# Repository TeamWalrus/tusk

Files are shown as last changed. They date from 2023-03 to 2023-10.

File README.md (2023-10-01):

# Tusk: Revamping an old weaponised RFID reader tool

This repo contains the hardware and software upgrades made to the original [Tastic RFID Thief project](https://bishopfox.com/resources/rfid-hacking-intro-to-tastic-rfid-thief), which was created by Francis Brown at Bishop Fox.

The core functionality of the project remains the same: a tool that allows red teamers to capture RFID access card credentials from several feet away. Additionally, the same readers are supported:

- HID Maxiprox 5375 (125kHz HID ProxII cards)
- HID Indala ASR-620 (125kHz Indala cards)
- HID iCLASS R90 (13.56mHz iClass cards)

## Overview of the upgrades

| Component | Description |
|:--- |:--- |
| Microcontroller Unit (MCU) | Replace the Arduino with an ESP32 |
| Batteries | Replace the AA with 27100's for the reader and 18650's for the MCU |
| Wireless Connectivity | The ESP32 has built-in WiFI capability |
| Web App | Simple react web interface |
| ~~Capability~~ | ~~Decode Gallagher 125kHz proximity cards (Cardax proprietary format)~~ |
| ~~Enclosure~~ | ~~3D printed enclosure for the PCB\*~~ |

\* One of the main issues with all previous build's I've seen, is the electronic components (microcontroller unit, buck converter and batteries) being housed inside the RFID reader. These components (specifically buck converters) create a lot of 'RF noise' - which interfere with the finely tuned RFID readers. This reduces the effective range of the reader, which can be the difference between capturing access card credentials or not. Housing these components externally, ensures the device operates at it's advertised range capability.

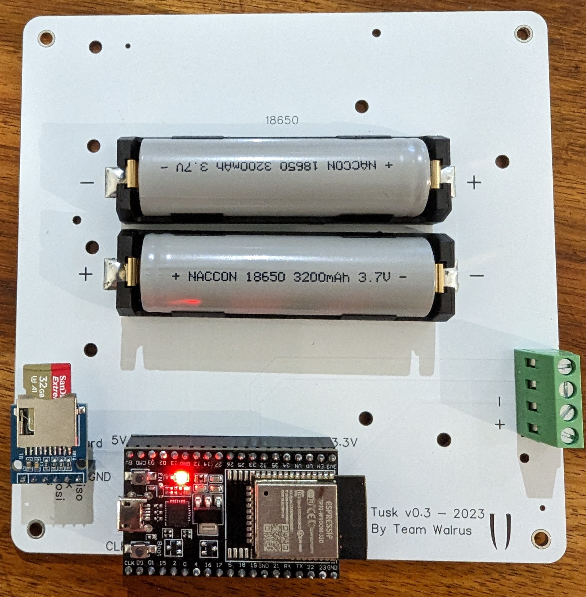
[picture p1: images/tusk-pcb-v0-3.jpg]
tusk-pcb


## Overview of the project structure

```
├── firmware                    # 
│   ├── interface               # react frontend web application
│   │   └── src
│   ├── data                    # build path of the react frontend
│   ├── src
│   │   └── main.cpp            # backend webserver + card handling code
│   ├── scripts
│   │   └── build_interface.py  # helper script to deploy react frontend to build path
├── hardware                    # gerber files, BOM, etc
```

## Build instructions: hardware

Gerber files, Bill of Materials (BOM), and Pick and Place files required to get the PCB manufactured can be found in the `/hardware` directory. This is a PCB that houses the batteries for the long range reader, ESP32 microcontroller unit, and sd-card reader. Note - some parts are not in the BOM as they were purchased directly from aliexpress (non-affiliate links below):

- ESP32-DevkitC-v4: https://www.aliexpress.com/item/4000090521976.html
- Mini SD card reader module: https://www.aliexpress.com/item/1865616455.html
- 21700 battery holder: https://www.aliexpress.com/item/1005003204083647.html

The tusk PCB uses 5 x 27100 li-ion batteries slots that will power the long range reader. That means the output voltage is 4.2V x 5 = 21V. This should be within the operating voltage for the long range readers listed above. However, I recommend checking this before hooking up your reader.

Once the PCB is assembled: 

- Connect the power from the PCB -> positive (+) and negative (-) from the block connector to the external reader
- Connect the data lines (`data0` and `data1`) from the block connector to the external reader

**Note**: the ESP32 footprint on the PCB is for an ESP32-DevKitC-V4. Older ESP32-DevKit-V1 will not fit.

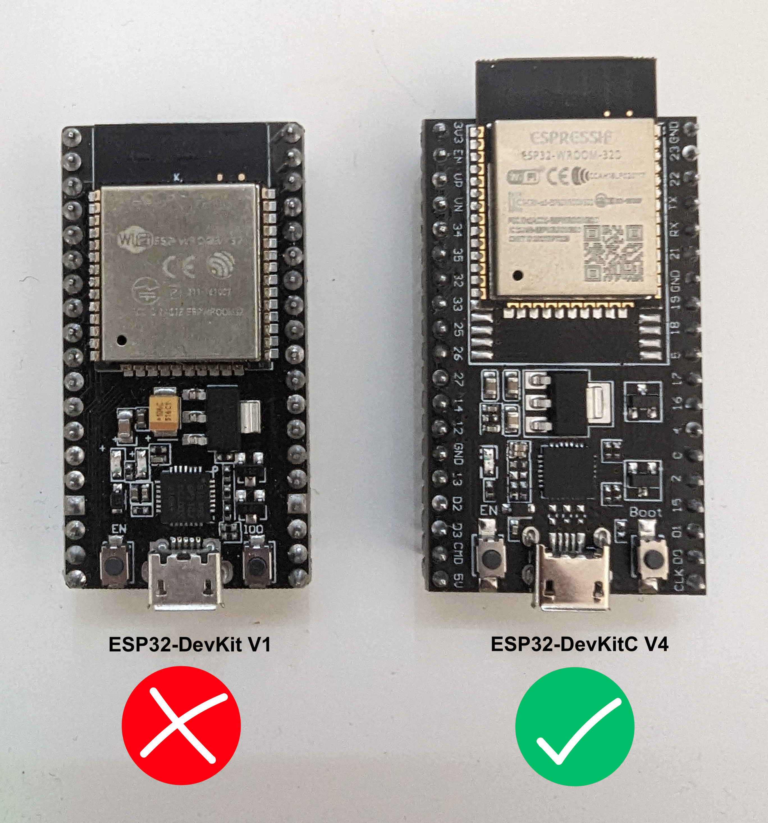
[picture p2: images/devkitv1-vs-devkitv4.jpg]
devkitv1-vs-devkitv4


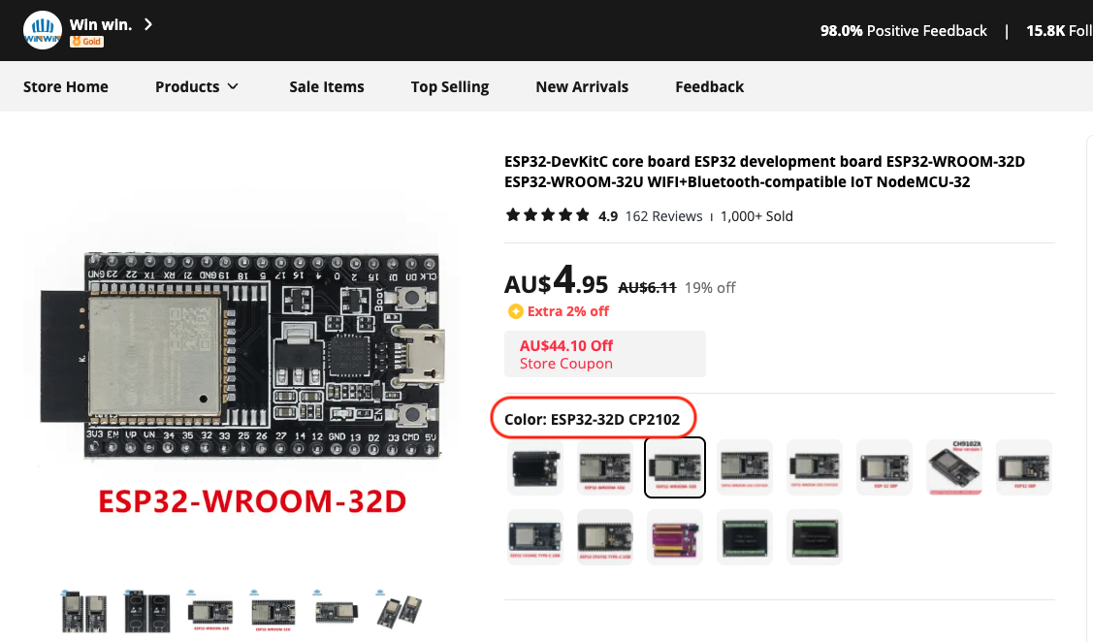
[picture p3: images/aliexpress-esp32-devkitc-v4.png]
aliexpress-esp32-devkitc-v4


## Build instructions: firmware

| Component | Description |
|:--- |:--- |
| `/firmware/src/main.cpp` | backend webserver and access card credentials handling code |
| `/firmware/interface/` | react frontend to display captured access card credentials  |

Change directory into `/firmware` and execute the following commands to flash the ESP32 firmware:

To build and upload the backend code: 

`pio run --target upload`

To build and upload the frontend react webapp: 

`pio run --target uploadfs`

### Tusk web interface

Clients connect to the ESP32 over WiFi and view captured card credentials via a react web application. The default values are as follows:

| Component | Details |
|:--- |:--- |
| WiFi SSID | `Tusk` |
| WiFi Password | `changeme` |
| URL | `http://192.168.100.1` |

## Legacy Operating Mode vs Future Operating Mode

The project currently operates in "legacy mode", which is based on receiving card credentials from the `data0` and `data1` output pins on the Maxiprox reader. 

This will eventually change and data will be sampled directly from the reader's microcontroller (pin `PD7` in the image below). The card sampling code is currently in another repo: https://github.com/TeamWalrus/tusk-sampler , and needs a few kinks ironed out. If you are interested in helping out, please check it out.

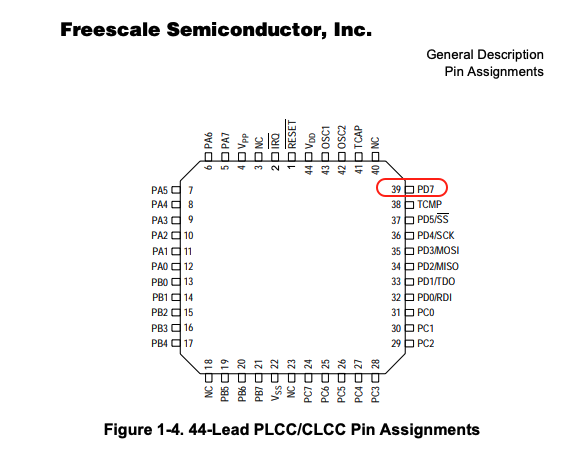
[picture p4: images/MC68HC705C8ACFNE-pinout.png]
MC68HC705C8ACFNE-pinout


Link for the MC68HC705C8ACFNE datasheet: https://www.allaboutcircuits.com/electronic-components/datasheet/MC68HC705C8ACFNE--NXP-Semiconductors/

## Acknowledgments

It's important to acknowledge previous work done on this project:

- Fran Brown: original Tastic RFID Thief: `https://www.bishopfox.com/resources/tools/rfid-hacking/attack-tools/`
- Folks who updated the original Arduino code:
  - ninewires: `https://github.com/ninewires/Prox_Thief/blob/master/Prox_Thief.ino`
  - ShakataGaNai: `https://gist.github.com/ShakataGaNai/4319d3e82a858c9d00c1d80f20da81a3`
- Other interesting projects / upgraded versions of the RFID Thief:
  - Mike Kelly's Wiegotcha: `https://github.com/lixmk/Wiegotcha`
  - Corey Harding's ESP-RFID-Thief: `https://github.com/exploitagency/ESP-RFID-Thief`

Thanks to my mate @megabug for always helping out with my projects :)

Thanks to my employer [Aura Information Security](https://www.aurainfosec.com/) for providing time for me to work on this project.

aura-logo

## Captured access card credentials format

Captured card credentials are written to the sd card in newline-delimited JSON (`cards.jsonl`). For example:

```
{"card_type":"hid","bit_length":26,"facility_code":123,"card_number":123123,"hex":"AAAAAAA","raw":"0010101010010011000101010"}
{"card_type":"gallagher","region_code":4,"bit_length":46,"facility_code":2222,"card_number":1111,"issue_level":3,"hex":"A38A8A4BA3A3A32C","raw":"101000110100010101100010101010010110101000110101000110101000110001011001"}
```

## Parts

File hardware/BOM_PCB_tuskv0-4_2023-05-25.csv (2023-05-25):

ID | Name | Designator | Footprint | Quantity | Manufacturer Part | Manufacturer | Supplier | Supplier Part | Price
1 | 21700 Battery Holder | U3,U6,U7,U8,U9 | 21700 BATTERY HOLDER | 5 | N/A | N/A | AliExpress | N/A
2 | PM254V-11-06-H85 | H1 | HDR-TH_6P-P2.54-V-F | 1 | PM254V-11-06-H85 | XFCN(兴飞) | LCSC | C2832269 | 0.119
3 | PM254-1-19-Z-8.5 | U1,U2 | HDR-TH_19P-P2.54-V-F | 2 | PM254-1-19-Z-8.5 | HCTL(华灿天禄) | LCSC | C2897382 | 0.272
4 | DB128V-5.0-4P | U5 | CONN-TH_DB128V-5.0-4P | 1 | DB128V-5.0-4P-GN-S | DIBO(地博电气) | LCSC | C424682 | 0.285
5 | BH-18650-B1BA002 | BT1,BT2 | BATTERY-SMD_18650-1S-L77.1-W20.7-1 | 2 | BH-18650-B1BA002 | MYOUNG(美阳) | LCSC | C2988620 | 1.33

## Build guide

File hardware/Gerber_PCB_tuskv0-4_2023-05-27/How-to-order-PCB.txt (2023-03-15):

How to Order PCB

Please refer to:
https://docs.easyeda.com/en/PCB/Order-PCB

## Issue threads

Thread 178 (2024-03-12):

Adding Debug instructions to README.md

evildaemond, 2024-03-12:
Adding some lines to the README.md file to assist with debugging, turns out SD Cards suck...

```text
### Debugging

The `sdCommand(): Card Failed! cmd: 0x00` error appears when the Micro SD does not connect to the ESP32

1. Check to make sure the Micro SD Card is installed
1. Using the continuity test on a Multimeter, verify if all traces are soldered properly

In the event of an error log which shows `sdcard_mount(): f_mount failed: (3) The physical drive cannot work`,

1. Make sure your Micro SD Card is formatted to FAT32
1. Check the Micro SD Card is suitable (Some forms of SanDisk SD cards such as the 32gb range will silently fail with this error)
```

dunderhay, 2024-11-12:
Awesome done!

Sorry only saw this now

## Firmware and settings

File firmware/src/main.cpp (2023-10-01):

// vim: ts=2 sw=2 et

#include "ArduinoJson.h"
#include "AsyncJson.h"
#include <Arduino.h>
#include <ESPAsyncWebServer.h>
#include <LittleFS.h>
#include <SD.h>
#include <SPI.h>
#include <WiFi.h>

// wifi config
// variables to save values from HTML form
String ssid;
String password;
String channel;
String hidessid;

// file paths on SD card to save wifi values permanently
const char *ssidPath = "/ssid.txt";
const char *passwordPath = "/password.txt";
const char *channelPath = "/channel.txt";
const char *hidessidPath = "/hidessid.txt";
const char *jsoncarddataPath = "/cards.jsonl";

IPAddress local_ip(192, 168, 100, 1);
IPAddress gateway(192, 168, 100, 1);
IPAddress subnet(255, 255, 255, 0);

// define CS pin for the SD card module
const int sd_cs = 5;

// general device settings
bool isCapturing = true;
String version = "0.1";

// read file from SD Card
String readSDFileLF(const char *path) {
  File file = SD.open(path);
  if (!file || file.isDirectory()) {
    Serial.println("[-] Failed to open file for reading");
    return String();
  }

  String fileContent;
  while (file.available()) {
    fileContent = file.readStringUntil('\n');
    break;
  }
  return fileContent;
  file.close();
}

// write file to SD Card
void writeSDFile(const char *path, const char *message) {
  File file = SD.open(path, FILE_WRITE);
  if (!file) {
    Serial.println("[-] Failed to open file for writing");
    return;
  }
  if (file.print(message)) {
    Serial.println("[+] File written");
  } else {
    Serial.println("[-] File write failed");
  }
  file.close();
}

// card reader config and variables

// max number of bits
#define MAX_BITS 100
// time to wait for another weigand pulse
#define WEIGAND_WAIT_TIME 3000

// stores all of the data bits
volatile unsigned char databits[MAX_BITS];
volatile unsigned int bitCount = 0;
// stores the last written card's data bits
unsigned char lastWrittenDatabits[MAX_BITS];
unsigned int lastWrittenBitCount = 0;

// goes low when data is currently being captured
volatile unsigned char flagDone;

// countdown until we assume there are no more bits
volatile unsigned int weigandCounter;

// card type
enum CardType {
  HID,
  GALLAGHER,
  UNKNOWN,
};
CardType cardType = UNKNOWN;

const char* cardTypeToString(CardType cardType) {
  switch (cardType) {
    case HID:
      return "hid";
    case GALLAGHER:
      return "gallagher";
    case UNKNOWN:
      return "unknown";
    default:
      return "Invalid Card Type";
  }
}

// decoded facility code
unsigned long facilityCode = 0;
// decoded card code
unsigned long cardNumber = 0;
// decoded issuer level
unsigned long regionCode = 0;
// decoded card code
unsigned long issueLevel = 0;
// hex data string
String hexCardData;
// raw data string
String rawCardData;

// breaking up card value into 2 chunks to create 10 char HEX value
volatile unsigned long bitHolder1 = 0;
volatile unsigned long bitHolder2 = 0;
unsigned long cardChunk1 = 0;
unsigned long cardChunk2 = 0;

// Define reader input pins
// card reader DATA0
#define DATA0 32
// card reader DATA1
#define DATA1 33

// process interupts
// interrupt that happens when INT0 goes low (0 bit)
void ISR_INT0() {
  bitCount++;
  flagDone = 0;

  if (bitCount < 23) {
    bitHolder1 = bitHolder1 << 1;
  } else {
    bitHolder2 = bitHolder2 << 1;
  }
  weigandCounter = WEIGAND_WAIT_TIME;
}

// interrupt that happens when INT1 goes low (1 bit)
void ISR_INT1() {
  if (bitCount < MAX_BITS) {
    databits[bitCount] = 1;
    bitCount++;
  }
  flagDone = 0;

  if (bitCount < 23) {
    bitHolder1 = bitHolder1 << 1;
    bitHolder1 |= 1;
  } else {
    bitHolder2 = bitHolder2 << 1;
    bitHolder2 |= 1;
  }

  weigandCounter = WEIGAND_WAIT_TIME;
}

// Print bits to serial (for debugging only)
void printCardData() {
  // ranges for "valid" bitCount are a bit larger for debugging
  if (bitCount > 20 && bitCount < 120) { // ignore data caused by noise
    Serial.print("[*] Bit length: ");
    Serial.println(bitCount);
    Serial.print("[*] Facility code: ");
    Serial.println(facilityCode);
    Serial.print("[*] Card number: ");
    Serial.println(cardNumber);
    if (cardType == GALLAGHER) {
      Serial.print("[*] Region Code: ");
      Serial.println(regionCode);
      Serial.print("[*] Issue Level: ");
      Serial.println(issueLevel);
    }
    Serial.print("[*] Hex: ");
    Serial.println(hexCardData);
    Serial.print("[*] Raw: ");
    Serial.println(rawCardData);
  }
}

// Process hid cards
unsigned long decodeHIDFacilityCode(unsigned int start, unsigned int end) {
  unsigned long HIDFacilityCode = 0;
  for (unsigned int i = start; i < end; i++) {
    HIDFacilityCode = (HIDFacilityCode << 1) | databits[i];
  }
  return HIDFacilityCode;
}

unsigned long decodeHIDCardNumber(unsigned int start, unsigned int end) {
  unsigned long HIDCardNumber = 0;
  for (unsigned int i = start; i < end; i++) {
    HIDCardNumber = (HIDCardNumber << 1) | databits[i];
  }
  return HIDCardNumber;
}

// Card value processing functions
// Function to append the card value (bitHolder1 and bitHolder2) to the
// necessary array then translate that to the two chunks for the card value that
// will be output
void setCardChunkBits(unsigned int cardChunk1Offset,
                      unsigned int bitHolderOffset,
                      unsigned int cardChunk2Offset) {
  for (int i = 19; i >= 0; i--) {
    if (i == 13 || i == cardChunk1Offset) {
      bitWrite(cardChunk1, i, 1);
    } else if (i > cardChunk1Offset) {
      bitWrite(cardChunk1, i, 0);
    } else {
      bitWrite(cardChunk1, i, bitRead(bitHolder1, i + bitHolderOffset));
    }
    if (i < bitHolderOffset) {
      bitWrite(cardChunk2, i + cardChunk2Offset, bitRead(bitHolder1, i));
    }
    if (i < cardChunk2Offset) {
      bitWrite(cardChunk2, i, bitRead(bitHolder2, i));
    }
  }
}

String prefixPad(const String &in, const char c, const size_t len) {
  String out = in;
  while (out.length() < len) {
    out = c + out;
  }
  return out;
}

void processHIDCard() {
  // bits to be decoded differently depending on card format length
  // see http://www.pagemac.com/projects/rfid/hid_data_formats for more info
  // also specifically: www.brivo.com/app/static_data/js/calculate.js
  // Example of full card value
  // |>   preamble   <| |>   Actual card value   <|
  // 000000100000000001 11 111000100000100100111000
  // |> write to chunk1 <| |>  write to chunk2   <|
  cardType = HID;

  unsigned int cardChunk1Offset, bitHolderOffset, cardChunk2Offset;

  switch (bitCount) {
  case 26:
    facilityCode = decodeHIDFacilityCode(1, 9);
    cardNumber = decodeHIDCardNumber(9, 25);
    cardChunk1Offset = 2;
    bitHolderOffset = 20;
    cardChunk2Offset = 4;
    break;

  case 27:
    facilityCode = decodeHIDFacilityCode(1, 13);
    cardNumber = decodeHIDCardNumber(13, 27);
    cardChunk1Offset = 3;
    bitHolderOffset = 19;
    cardChunk2Offset = 5;
    break;

  case 29:
    facilityCode = decodeHIDFacilityCode(1, 13);
    cardNumber = decodeHIDCardNumber(13, 29);
    cardChunk1Offset = 5;
    bitHolderOffset = 17;
    cardChunk2Offset = 7;
    break;

  case 30:
    facilityCode = decodeHIDFacilityCode(1, 13);
    cardNumber = decodeHIDCardNumber(13, 29);
    cardChunk1Offset = 6;
    bitHolderOffset = 16;
    cardChunk2Offset = 8;
    break;

  case 31:
    facilityCode = decodeHIDFacilityCode(1, 5);
    cardNumber = decodeHIDCardNumber(5, 28);
    cardChunk1Offset = 7;
    bitHolderOffset = 15;
    cardChunk2Offset = 9;
    break;

  case 32:
    facilityCode = decodeHIDFacilityCode(1, 13);
    cardNumber = decodeHIDCardNumber(13, 31);
    cardChunk1Offset = 8;
    bitHolderOffset = 14;
    cardChunk2Offset = 10;
    break;

  case 33:
    facilityCode = decodeHIDFacilityCode(1, 8);
    cardNumber = decodeHIDCardNumber(8, 32);
    cardChunk1Offset = 9;
    bitHolderOffset = 13;
    cardChunk2Offset = 11;
    break;

  case 34:
    facilityCode = decodeHIDFacilityCode(1, 17);
    cardNumber = decodeHIDCardNumber(17, 33);
    cardChunk1Offset = 10;
    bitHolderOffset = 12;
    cardChunk2Offset = 12;
    break;

  case 35:
    facilityCode = decodeHIDFacilityCode(2, 14);
    cardNumber = decodeHIDCardNumber(14, 34);
    cardChunk1Offset = 11;
    bitHolderOffset = 11;
    cardChunk2Offset = 13;
    break;

  case 36:
    facilityCode = decodeHIDFacilityCode(21, 33);
    cardNumber = decodeHIDCardNumber(1, 17);
    cardChunk1Offset = 12;
    bitHolderOffset = 10;
    cardChunk2Offset = 14;
    break;

  default:
    Serial.println("[-] Unsupported bitCount for HID card");
    return;
  }

  setCardChunkBits(cardChunk1Offset, bitHolderOffset, cardChunk2Offset);
  hexCardData =
      String(cardChunk1, HEX) + prefixPad(String(cardChunk2, HEX), '0', 6);
}

// gallagher cardholder credential data structure
struct CardholderCredentials {
  int region_code;
  int facility_code;
  int card_number;
  int issue_level;
};

// gallagher descramble function to deobfuscate card data
byte descramble(byte arr) {
  byte lut[] = {
      0x2f, 0x6e, 0xdd, 0xdf, 0x1d, 0x0f, 0xb0, 0x76, 0xad, 0xaf, 0x7f, 0xbb,
      0x77, 0x85, 0x11, 0x6d, 0xf4, 0xd2, 0x84, 0x42, 0xeb, 0xf7, 0x34, 0x55,
      0x4a, 0x3a, 0x10, 0x71, 0xe7, 0xa1, 0x62, 0x1a, 0x3e, 0x4c, 0x14, 0xd3,
      0x5e, 0xb2, 0x7d, 0x56, 0xbc, 0x27, 0x82, 0x60, 0xe3, 0xae, 0x1f, 0x9b,
      0xaa, 0x2b, 0x95, 0x49, 0x73, 0xe1, 0x92, 0x79, 0x91, 0x38, 0x6c, 0x19,
      0x0e, 0xa9, 0xe2, 0x8d, 0x66, 0xc7, 0x5a, 0xf5, 0x1c, 0x80, 0x99, 0xbe,
      0x4e, 0x41, 0xf0, 0xe8, 0xa6, 0x20, 0xab, 0x87, 0xc8, 0x1e, 0xa0, 0x59,
      0x7b, 0x0c, 0xc3, 0x3c, 0x61, 0xcc, 0x40, 0x9e, 0x06, 0x52, 0x1b, 0x32,
      0x8c, 0x12, 0x93, 0xbf, 0xef, 0x3b, 0x25, 0x0d, 0xc2, 0x88, 0xd1, 0xe0,
      0x07, 0x2d, 0x70, 0xc6, 0x29, 0x6a, 0x4d, 0x47, 0x26, 0xa3, 0xe4, 0x8b,
      0xf6, 0x97, 0x2c, 0x5d, 0x3d, 0xd7, 0x96, 0x28, 0x02, 0x08, 0x30, 0xa7,
      0x22, 0xc9, 0x65, 0xf8, 0xb7, 0xb4, 0x8a, 0xca, 0xb9, 0xf2, 0xd0, 0x17,
      0xff, 0x46, 0xfb, 0x9a, 0xba, 0x8f, 0xb6, 0x69, 0x68, 0x8e, 0x21, 0x6f,
      0xc4, 0xcb, 0xb3, 0xce, 0x51, 0xd4, 0x81, 0x00, 0x2e, 0x9c, 0x74, 0x63,
      0x45, 0xd9, 0x16, 0x35, 0x5f, 0xed, 0x78, 0x9f, 0x01, 0x48, 0x04, 0xc1,
      0x33, 0xd6, 0x4f, 0x94, 0xde, 0x31, 0x9d, 0x0a, 0xac, 0x18, 0x4b, 0xcd,
      0x98, 0xb8, 0x37, 0xa2, 0x83, 0xec, 0x03, 0xd8, 0xda, 0xe5, 0x7a, 0x6b,
      0x53, 0xd5, 0x15, 0xa4, 0x43, 0xe9, 0x90, 0x67, 0x58, 0xc0, 0xa5, 0xfa,
      0x2a, 0xb1, 0x75, 0x50, 0x39, 0x5c, 0xe6, 0xdc, 0x89, 0xfc, 0xcf, 0xfe,
      0xf9, 0x57, 0x54, 0x64, 0xa8, 0xee, 0x23, 0x0b, 0xf1, 0xea, 0xfd, 0xdb,
      0xbd, 0x09, 0xb5, 0x5b, 0x05, 0x86, 0x13, 0xf3, 0x24, 0xc5, 0x3f, 0x44,
      0x72, 0x7c, 0x7e, 0x36};

  return lut[arr];
}

// deobfuscate Gallagher cardholder credentials
CardholderCredentials deobfuscate_cardholder_credentials(byte *bytes) {
  byte arr[8];
  for (int i = 0; i < 8; i++) {
    arr[i] = descramble(bytes[i]);
  }

  CardholderCredentials credentials;
  // 4bit region code
  credentials.region_code = (arr[3] & 0x1E) >> 1;
  // 16bit facility code
  credentials.facility_code =
      ((arr[5] & 0x0F) << 12) | (arr[1] << 4) | ((arr[7] >> 4) & 0x0F);
  // 24bit card number
  credentials.card_number = (arr[0] << 16) | ((arr[4] & 0x1F) << 11) |
                            (arr[2] << 3) | ((arr[3] & 0xE0) >> 5);
  // 4bit issue level
  credentials.issue_level = (arr[7] & 0x0F);

  return credentials;
}

bool decodeError = false;
// Function to decode raw Gallagher Cardax 125kHz card data
byte *decode_cardax_125khz(String data) {
  String magic_prefix = "01111111111010";
  int i = data.indexOf(magic_prefix);

  if (i == -1) {
    Serial.println(
        "[!] Magic prefix not found - not a valid gallagher cardax card");
    decodeError = true;
    return nullptr;
  }

  data = data.substring(i + 16);
  data = data.substring(0, 9 * 8 + 8);

  if (data.length() != 9 * 8 + 8) {
    Serial.println("[!] Invalid gallagher card data length");
    decodeError = true;
    return nullptr;
  }

  String b = "";

  while (b.length() < 64 + 8) {
    String n = data.substring(9 * b.length() / 8);
    if (b.length() < 64) {
      if (n.charAt(7) == n.charAt(8)) {
        Serial.println("[!] Invalid gallagher data");
        decodeError = true;
        return nullptr;
      }
    }
    b += n.substring(0, 8);
  }

  uint64_t n = strtoull(b.substring(0, 64).c_str(), NULL, 2);

  /*
  TODO: the checksum always fails
  byte check_sum = 0x2C;
  byte xcc[] = {0x7, 0xE, 0x1C, 0x38, 0x70, 0xE0, 0xC7, 0x89};

  for (int c = 0; c < 8; c++) {
    byte ncs = check_sum ^ ((byte*)&n)[c];
    check_sum = ncs;
    for (int i = 0; i < 8; i++) {
      if (ncs & (1 << i)) {
        check_sum ^= xcc[i];
      }
    }
  }

  if (strtoull(b.substring(0, 64).c_str(), NULL, 2) != check_sum) {
    Serial.println("[-] Checksum did not match");
    decodeError = true;
    return nullptr;
  }
  */

  static byte byteArr[8];
  for (int i = 0; i < 8; i++) {
    byteArr[i] = (n >> (56 - i * 8)) & 0xFF;
  }

  return byteArr;
}

void processGallagherCard() {
  cardType = GALLAGHER;
  byte *hex = decode_cardax_125khz(rawCardData);
  if (decodeError) {
    Serial.println("[!] Error occurred during gallagher (cardax) decoding.");
  } else {
    for (int i = 0; i < 8; i++) {
      hexCardData += String(hex[i], HEX);
    }
    CardholderCredentials credentials = deobfuscate_cardholder_credentials(hex);
    regionCode = credentials.region_code;
    facilityCode = credentials.facility_code;
    cardNumber = credentials.card_number;
    issueLevel = credentials.issue_level;
  }
}

void processCardData() {
  rawCardData = "";
  for (unsigned int i = 0; i < bitCount; i++) {
    rawCardData += String(databits[i]);
  }

  if (bitCount >= 26 && bitCount <= 36) {
    processHIDCard();
  }

  if (bitCount == 96) {
    processGallagherCard();
  }
}

bool cardDataChanged() {
  // check if the newly read card's bits are the same as the previously
  // written card's bits
  unsigned char i;
  bool different = false;

  if (bitCount == lastWrittenBitCount) {
    for (i = 0; i < bitCount; i++) {
      if (databits[i] != lastWrittenDatabits[i]) {
        different = true;
        break;
      }
    }
  } else {
    different = true;
  }

  return different;
}

void updateLastWrittenCardData() {
  unsigned char i;
  lastWrittenBitCount = bitCount;
  for (i = 0; i < bitCount; i++) {
    lastWrittenDatabits[i] = databits[i];
  }
}

void clearDatabits() {
  for (unsigned char i = 0; i < MAX_BITS; i++) {
    databits[i] = 0;
  }
}

// reset variables and prepare for the next card read
void cleanupCardData() {
  cardType = UNKNOWN;
  rawCardData = "";
  hexCardData = "";
  bitCount = 0;
  facilityCode = 0;
  cardNumber = 0;
  regionCode = 0;
  issueLevel = 0;
  bitHolder1 = 0;
  bitHolder2 = 0;
  cardChunk1 = 0;
  cardChunk2 = 0;
}

/* #####----- Write to SD card -----##### */
void writeToSD() {
  File SDFile = SD.open("/cards.jsonl", FILE_APPEND);
  if (SDFile) {
    DynamicJsonDocument doc(1024);
    doc["card_type"] = cardTypeToString(cardType);
    doc["bit_length"] = bitCount;
    doc["facility_code"] = facilityCode;
    doc["card_number"] = cardNumber;
    if (cardType == GALLAGHER) {
      doc["issue_level"] = issueLevel;
      doc["region_code"] = regionCode;
    }
    doc["raw"] = rawCardData;
    doc["hex"] = hexCardData;
    Serial.println("[+] New Card Read: ");
    serializeJsonPretty(doc, Serial);
    if (serializeJson(doc, SDFile) == 0) {
      Serial.println("[-] SD Card: Failed to write json card data to file");
    }
    SDFile.print("\n");
    SDFile.close();
    Serial.println("\n[+] SD Card: Data Written to SD Card");
  }
}

// webserver setup and config
AsyncWebServer server(80);

void logRequest(const String &url) {
  Serial.println("[*] Webserver: Requested url: " + url);
  Serial.println("[*] Webserver: Serving gzipped file: " + url + ".gz");
}

String getUrlExtension(const String &url) {
  String extension = url.substring(url.lastIndexOf('.') + 1);

  if (extension == "html" || extension == "htm")
    return "text/html";
  else if (extension == "css")
    return "text/css";
  else if (extension == "js")
    return "text/javascript";
  else if (extension == "json")
    return "application/json";
  else if (extension == "jpg" || extension == "jpeg")
    return "image/jpeg";
  else if (extension == "png")
    return "image/png";
  else if (extension == "svg")
    return "image/svg+xml";
  else
    return "text/plain";
}

void handleGzippedFile(AsyncWebServerRequest *request, const String &url,
                       const String &contentType) {
  logRequest(url);
  AsyncWebServerResponse *response =
      request->beginResponse(LittleFS, url + ".gz", contentType);
  response->addHeader("Content-Encoding", "gzip");
  request->send(response);
}

void sendJsonResponse(AsyncWebServerRequest *request,
                      DynamicJsonDocument &json) {
  AsyncResponseStream *response =
      request->beginResponseStream("application/json");
  serializeJson(json, *response);
  request->send(response);
}

void handleGeneralSettingsGet(AsyncWebServerRequest *request) {
  DynamicJsonDocument json(200);
  json["capturing"] = isCapturing;
  json["version"] = version;
  sendJsonResponse(request, json);
}

void handleGeneralSettingsPost(AsyncWebServerRequest *request) {
  int params = request->params();
  for (int i = 0; i < params; i++) {
    AsyncWebParameter *p = request->getParam(i);
    if (p->isPost()) {
      if (p->name() == "capturing") {
        String newCapturingState = p->value().c_str();
        if (newCapturingState == "true") {
          isCapturing = true;
        } else if (newCapturingState == "false") {
          isCapturing = false;
        }
      }
      Serial.printf("[+] Webserver: FormData - [%s]: %s\n", p->name().c_str(),
                    p->value().c_str());
    }
  }
  request->send(200, "text/plain", "General settings updated");
}

void handleJsonFileResponse(AsyncWebServerRequest *request,
                            const String &path) {
  AsyncResponseStream *response =
      request->beginResponseStream("application/json");
  DynamicJsonDocument json(512);

  if (path == "littlefsinfo") {
    json["totalBytes"] = LittleFS.totalBytes();
    json["usedBytes"] = LittleFS.usedBytes();
  } else if (path == "sdcardinfo") {
    json["totalBytes"] = SD.totalBytes();
    json["usedBytes"] = SD.usedBytes();
  }

  serializeJson(json, *response);
  request->send(response);
}

void handleCardDataGet(AsyncWebServerRequest *request) {
  File SDFile = SD.open("/cards.jsonl", FILE_READ);
  String cardData;

  if (SDFile) {
    while (SDFile.available()) {
      cardData = SDFile.readString();
    }
    SDFile.close();
  } else {
    Serial.println("[-] SD Card: error opening json data");
  }

  AsyncWebServerResponse *response =
      request->beginResponse(200, "application/x-ndjson", cardData);
  request->send(response);
}

void handleCardDataPost(AsyncWebServerRequest *request) {
  writeSDFile(jsoncarddataPath, "");
  lastWrittenBitCount = 0;
  for (unsigned char i = 0; i < MAX_BITS; i++) {
    lastWrittenDatabits[i] = 0;
  }

  AsyncWebServerResponse *response =
      request->beginResponse(200, "text/plain", "All card data deleted!");
  request->send(response);
}

void handleWiFiConfigGet(AsyncWebServerRequest *request) {
  AsyncResponseStream *response =
      request->beginResponseStream("application/json");
  DynamicJsonDocument json(512);
  json["ssid"] = ssid;
  json["password"] = password;
  json["channel"] = channel;
  json["hidessid"] = hidessid;
  serializeJson(json, *response);
  request->send(response);
}

void handleWifiConfigPost(AsyncWebServerRequest *request) {
  int params = request->params();

  for (int i = 0; i < params; i++) {
    AsyncWebParameter *p = request->getParam(i);
    if (p->isPost()) {
      if (p->name() == "ssid") {
        ssid = p->value().c_str();
        writeSDFile(ssidPath, ssid.c_str());
      }
      if (p->name() == "password") {
        password = p->value().c_str();
        writeSDFile(passwordPath, password.c_str());
      }
      if (p->name() == "channel") {
        channel = p->value().c_str();
        writeSDFile(channelPath, channel.c_str());
      }
      if (p->name() == "hidessid") {
        hidessid = p->value().c_str();
        if (hidessid == "on") {
          writeSDFile(hidessidPath, "1");
        } else {
          writeSDFile(hidessidPath, "0");
        }
      }
      Serial.printf("[+] Webserver: FormData - [%s]: %s\n", p->name().c_str(),
                    p->value().c_str());
    }
    request->send(200, "text/plain", "WiFi config updated. Rebooting now");
  }
}
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
void loop() {
  if (isCapturing) {

    if (!flagDone) {
      if (--weigandCounter == 0)
        flagDone = 1;
    }

    // if there are bits and the weigand counter went out
    if (bitCount > 0 && flagDone) {

      // Check if card data has changed
      if (cardDataChanged()) {
        processCardData();
        printCardData();

        // check if card data is valid before writing to SD card
        // bitCount either within HID range or equal to Gallagher
        if (bitCount >= 26 && bitCount <= 36 || bitCount == 96) {
          if (facilityCode != 0 || cardNumber != 0) {
            writeToSD();
            updateLastWrittenCardData();
          } else {
            Serial.println("[-] Tusk: Invalid card data detected - blank "
                           "facility code or card number");
          }
        } else {
          Serial.println("[-] Tusk: Invalid card data detected - bitCount not "
                         "within valid range");
        }
      }

      cleanupCardData();
      clearDatabits();
    }
  } else {
    // not capturing data - do nothing
    Serial.println("[-] Tusk: Not capturing data");
    delay(60000);
  }
}

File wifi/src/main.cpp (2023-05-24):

#include <Arduino.h>
#include <SD.h>
#include <SPI.h>
#include <WiFi.h>
#include <LittleFS.h>
#include <ESPAsyncWebServer.h>
#include "AsyncJson.h"
#include "ArduinoJson.h"

// Uncomment for debugging / verbose messages
// #define VERBOSE

// WiFi config
// Variables to save values from HTML form
String ssid;
String password;
String channel;
String hidessid;

// File paths on SD card to save wifi values permanently
const char *ssidPath = "/ssid.txt";
const char *passwordPath = "/password.txt";
const char *channelPath = "/channel.txt";
const char *hidessidPath = "/hidessid.txt";
const char *jsoncarddataPath = "/cards.jsonl";

IPAddress local_ip(192, 168, 100, 1);
IPAddress gateway(192, 168, 100, 1);
IPAddress subnet(255, 255, 255, 0);

// Define CS pin for the SD card module
const int sd_cs = 5;

// Webserver config /
AsyncWebServer server(80);

// Read File from SD Card
String readSDFile(const char *path)
{
  File file = SD.open(path);
  if (!file || file.isDirectory())
  {
#ifdef VERBOSE
    Serial.println("[-] Failed to open file for reading");
#endif
    return String();
  }

  String fileContent;
  while (file.available())
  {
    fileContent = file.readStringUntil('\n');
    break;
  }
  return fileContent;
}

// Write file to SD Card
void writeSDFile(const char *path, const char *message)
{
  File file = SD.open(path, FILE_WRITE);
  if (!file)
  {
#ifdef VERBOSE
    Serial.println("[-] Failed to open file for writing");
#endif
    return;
  }
  if (file.print(message))
  {
#ifdef VERBOSE
    Serial.println("[+] File written");
#endif
  }
  else
  {
#ifdef VERBOSE
    Serial.println("[-] File write failed");
#endif
  }
}

/* #####----- Card Reader Config -----##### */
// Card Reader variables
#define MAX_BITS 100           // max number of bits
#define WEIGAND_WAIT_TIME 3000 // time to wait for another weigand pulse

unsigned char databits[MAX_BITS]; // stores all of the data bits
volatile unsigned int bitCount = 0;
unsigned char flagDone;       // goes low when data is currently being captured
unsigned int weigand_counter; // countdown until we assume there are no more bits

volatile unsigned long facilityCode = 0; // decoded facility code
volatile unsigned long cardCode = 0;     // decoded card code

// Breaking up card value into 2 chunks to create 10 char HEX value
volatile unsigned long bitHolder1 = 0;
volatile unsigned long bitHolder2 = 0;
volatile unsigned long cardChunk1 = 0;
volatile unsigned long cardChunk2 = 0;

// Define reader input pins
#define DATA0 32 // card reader DATA0
#define DATA1 33 // card reader DATA1

/* #####----- Process interupts -----##### */
// interrupt that happens when INT0 goes low (0 bit)
void ISR_INT0()
{
  bitCount++;
  flagDone = 0;

  if (bitCount < 23)
  {
    bitHolder1 = bitHolder1 << 1;
  }
  else
  {
    bitHolder2 = bitHolder2 << 1;
  }
  weigand_counter = WEIGAND_WAIT_TIME;
}

// interrupt that happens when INT1 goes low (1 bit)
void ISR_INT1()
{
  databits[bitCount] = 1;
  bitCount++;
  flagDone = 0;

  if (bitCount < 23)
  {
    bitHolder1 = bitHolder1 << 1;
    bitHolder1 |= 1;
  }
  else
  {
    bitHolder2 = bitHolder2 << 1;
    bitHolder2 |= 1;
  }

  weigand_counter = WEIGAND_WAIT_TIME;
}

/* #####----- Print bits function -----##### */
void printBits()
{
  if (bitCount >= 26)
  { // ignore data caused by noise
    Serial.println("bit length: " + bitCount);
    Serial.println("facility code: " + facilityCode);
    Serial.println("card number: " + cardCode);
    Serial.print("Hex: ");
    Serial.print(cardChunk1, HEX);
    Serial.println(cardChunk2, HEX);
  }
}

/* #####----- Process card format function -----##### */
void getCardNumAndSiteCode()
{
  unsigned char i;

  // bits to be decoded differently depending on card format length
  // see http://www.pagemac.com/projects/rfid/hid_data_formats for more info
  // also specifically: www.brivo.com/app/static_data/js/calculate.js
  switch (bitCount)
  {

  ///////////////////////////////////////
  // standard 26 bit format
  // facility code = bits 2 to 9
  case 26:
    for (i = 1; i < 9; i++)
    {
      facilityCode <<= 1;
      facilityCode |= databits[i];
    }

    // card code = bits 10 to 23
    for (i = 9; i < 25; i++)
    {
      cardCode <<= 1;
      cardCode |= databits[i];
    }
    break;

  ///////////////////////////////////////
  // 33 bit HID Generic
  case 33:
    for (i = 1; i < 8; i++)
    {
      facilityCode <<= 1;
      facilityCode |= databits[i];
    }

    // card code
    for (i = 8; i < 32; i++)
    {
      cardCode <<= 1;
      cardCode |= databits[i];
    }
    break;

  ///////////////////////////////////////
  // 34 bit HID Generic
  case 34:
    for (i = 1; i < 17; i++)
    {
      facilityCode <<= 1;
      facilityCode |= databits[i];
    }

    // card code
    for (i = 17; i < 33; i++)
    {
      cardCode <<= 1;
      cardCode |= databits[i];
    }
    break;

  ///////////////////////////////////////
  // 35 bit HID Corporate 1000 format
  // facility code = bits 2 to 14
  case 35:
    for (i = 2; i < 14; i++)
    {
      facilityCode <<= 1;
      facilityCode |= databits[i];
    }

    // card code = bits 15 to 34
    for (i = 14; i < 34; i++)
    {
      cardCode <<= 1;
      cardCode |= databits[i];
    }
    break;
  }
  return;
}
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

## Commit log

2023-04-03 initial wifi + react webapp commit
    [partitions.csv]
2023-04-12 revert to json from jsonl
    [main.cpp]
2023-04-13 use ndjson instead of giant json object - avoid memory issues with large data set
    [main.cpp]
2023-04-13 hardware: move sd card mount and remove additional GND traces
    [BOM_PCB_tusk_2023-02-22.csv, BOM_PCB_tusk_2023-04-13.csv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]
2023-04-15 fixes #10
    [Drill_NPTH_Through.DRL, Drill_PTH_Through.DRL, Drill_PTH_Through_Via.DRL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]
2023-04-16 remove prints from interupts because no
2023-05-25 add v0.3 hardware files
    [BOM_PCB_tusk_2023-04-13.csv, BOM_PCB_tusk_2023-05-25.csv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]
2023-05-26 Don't overflow databits array (fixes #11)
    [main.cpp]
2023-05-26 Correctly pad second card chunk (fixes #6)
    [main.cpp]
2023-05-26 De-duplicate written card data (fixes #14)
    [main.cpp]
2023-05-26 Fix volatile-ness of some globals
    [main.cpp]
2023-05-27 use toggle switch for hide wifi ap setting
2023-05-27 allow most debug messages by default and only require define for very verbose errors
    [main.cpp]
2023-05-27 add data1 and data0 labels to pcb (fixes #27)
    [BOM_PCB_tuskv0-4_2023-05-25.csv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]
2023-05-28 use modal for delete all cards confirmation (fixes #31)
    [main.cpp]
2023-05-29 get current wifi config from files on sd card (fixes #30)
    [main.cpp]
2023-06-06 submit wifi update form via fetch (fixes #36)
    [main.cpp]
2023-06-06 add route to favicon (fixes #35)
    [main.cpp]
2023-06-07 add toast notification after wifi config updated and add reboot device route (fixes #32)
    [main.cpp]
2023-06-13 remove need to define verbose error flag
    [main.cpp]
2023-06-18 Add a flag to identify the card types (fixes #38)
    [main.cpp]
2023-06-18 reformatting and added cardData and filter to the useMemo hook
2023-06-19 start working on handling gallagher cards (issue #22)
    [main.cpp]
2023-07-03 fixes #26 fixes #55 fixes #56 fixes #57 fixes #58
    [main.cpp]
2023-07-06 fixes #47 and fixes #64
    [main.cpp]
